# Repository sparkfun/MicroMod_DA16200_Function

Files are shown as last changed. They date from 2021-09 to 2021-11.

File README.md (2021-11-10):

SparkFun MicroMod DA16200 Function Board
========================================

SparkFun MicroMod DA16200 Function Board

[*SparkFun MicroMod DA16200 Function Board (18594)*](https://www.sparkfun.com/products/18594)

The SparkFun MicroMod DA16200 Function Board adds a fully integrated WiFi module with a 40MHz crystal oscillator, 32.768KHz RTC clock, RF Lumped RF filter, 4MB flash memory, and an on-board chip antenna to any MicroMod project. With the addition of JTAG connectors for deep dive programming, you've got everything you need to get your MicroMod setup ready for your next IoT project. 

The SparkFun MicroMod DA16200 Function Board is ideal for MicroMod projects involving door locks, thermostats, sensors, pet trackers, and other home IoT projects, thanks in part to the multiple sleep modes that allow you to take advantage of current draws as low as 0.2uA-3.5uA.

Additionally, the DA16200 module's certified WiFi alliance for IEEE802.11b/g/n, WiFi Direct, and WPS functionalities means that it has been approved for use by multiple countries and using the WiFi Alliance transfer policy, each WiFi Certification can be transferred without being tested again. 

Repository Contents
-------------------
* **/Hardware** - Eagle design files (.brd, .sch)

Documentation
--------------
* **[Hookup Guide](https://learn.sparkfun.com/tutorials/micromod-wifi-function-board---da16200-hookup-guide)** - Basic hookup guide for the SparkFun MicroMod DA16200 Function Board.

License Information
-------------------

This product is _**open source**_! 

Please review the LICENSE.md file for license information. 

If you have any questions or concerns on licensing, please contact technical support on our [SparkFun forums](https://forum.sparkfun.com/viewforum.php?f=152).

Distributed as-is; no warranty is given.

- Your friends at SparkFun.

_<COLLABORATION CREDIT>_

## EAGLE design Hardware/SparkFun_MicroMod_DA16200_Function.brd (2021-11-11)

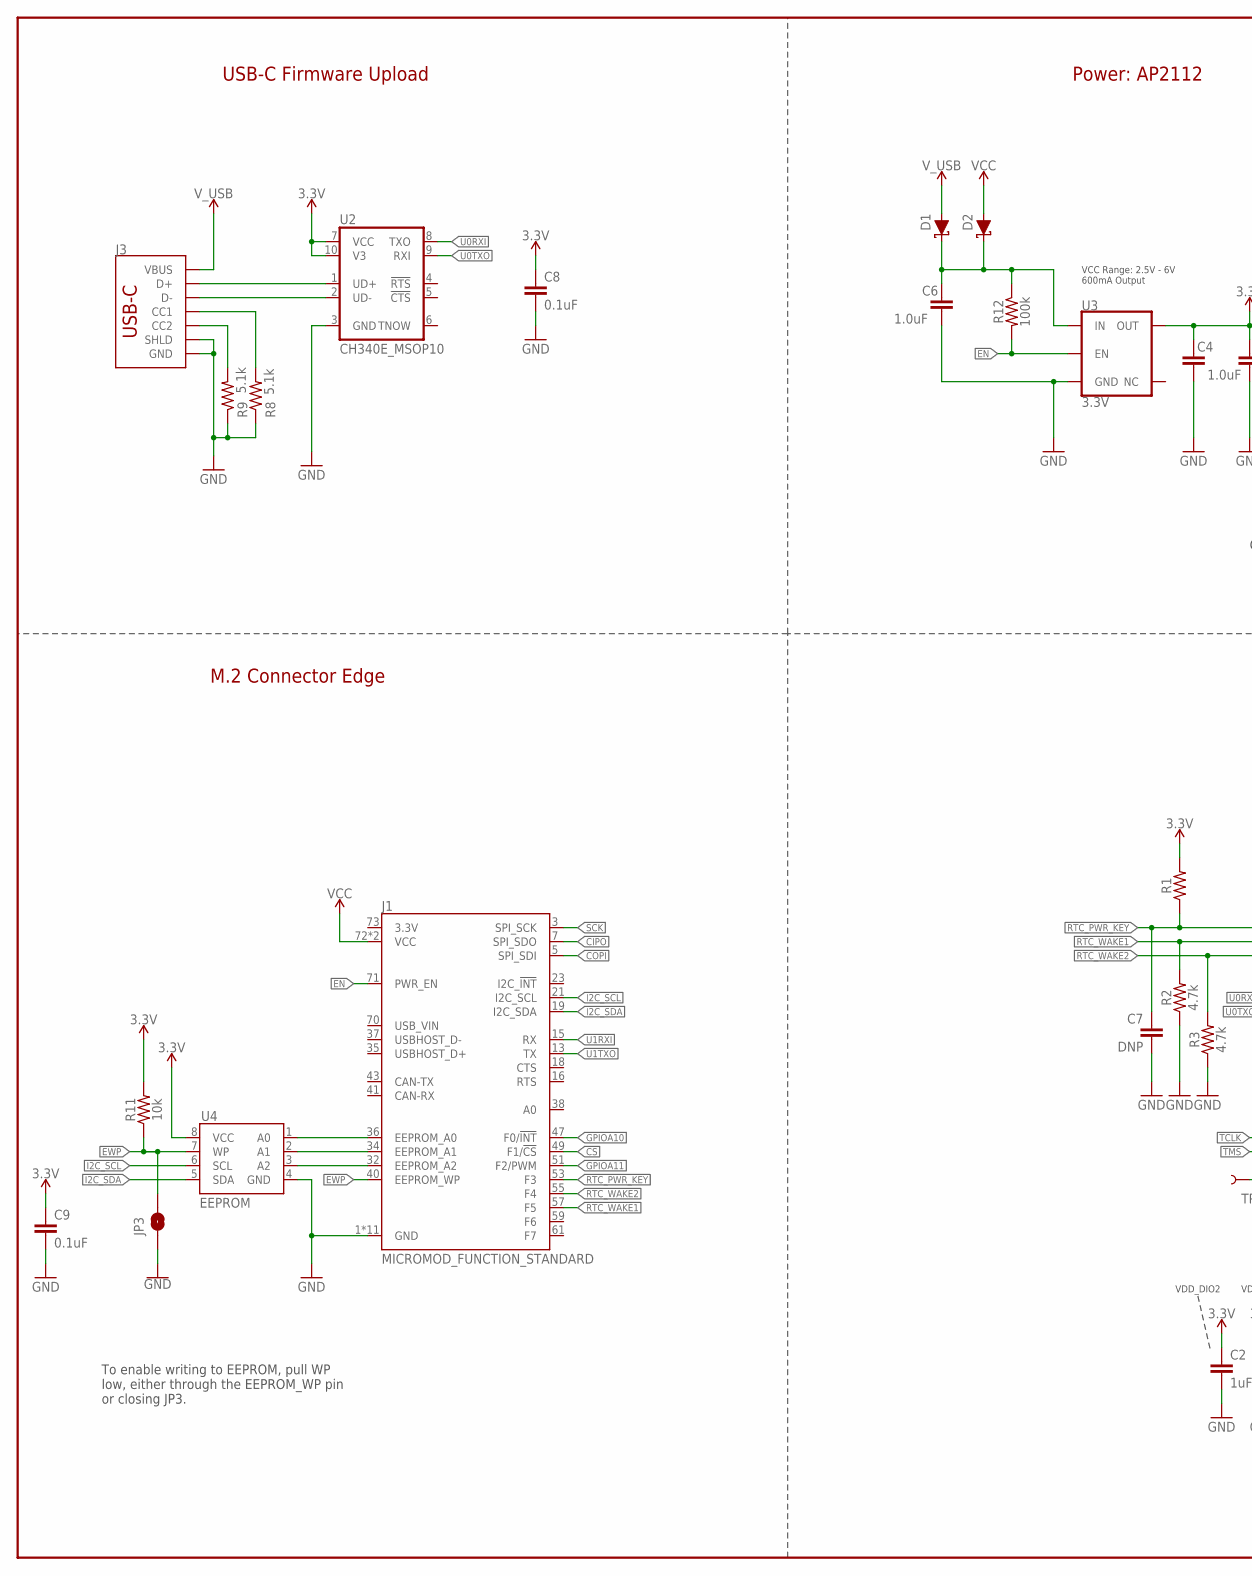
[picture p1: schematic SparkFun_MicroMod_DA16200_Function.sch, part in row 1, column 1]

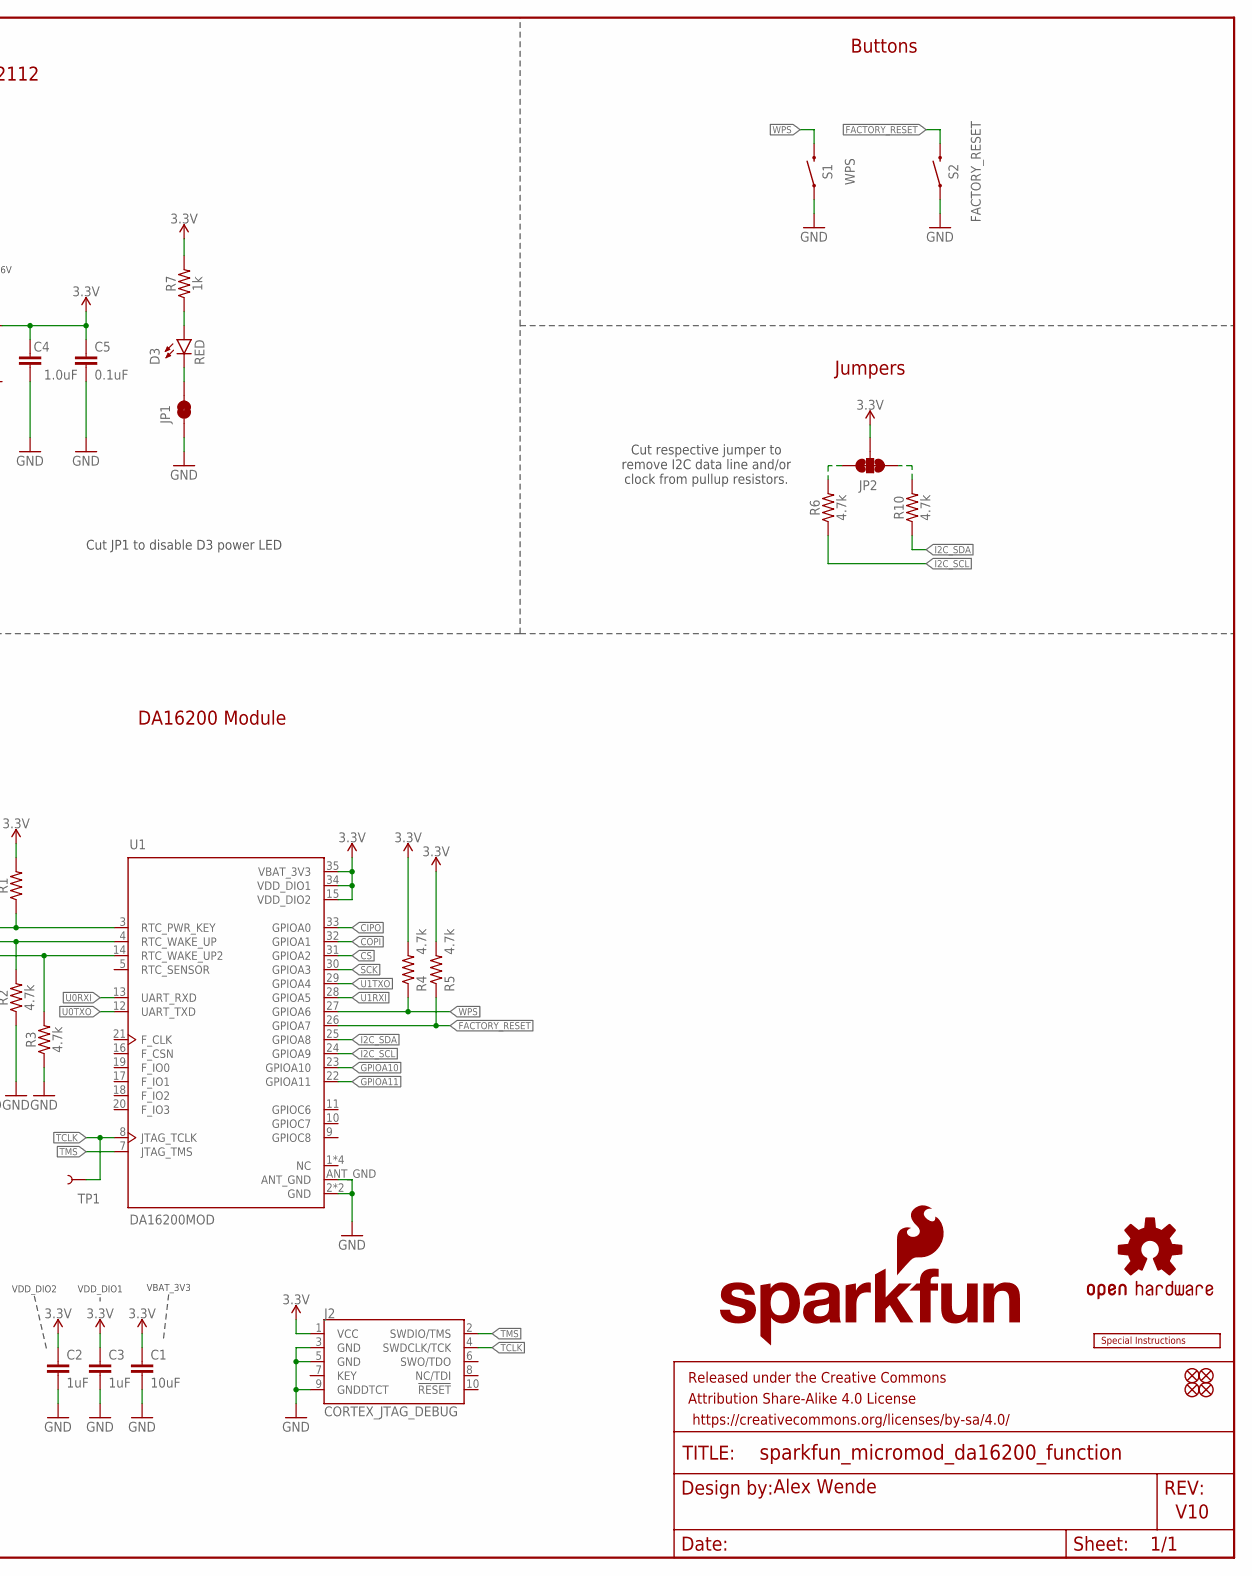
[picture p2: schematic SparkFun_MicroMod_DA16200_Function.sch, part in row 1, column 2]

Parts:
C1: 10uF; 0603
C2, C3: 1uF; 0603
C4, C6: 1.0uF; 0603
C5, C8, C9: 0.1uF; 0603
C7: DNP; 0603
D1, D2: DIODE-SCHOTTKY-BAT60A; SOD-323
D3: RED; LED-0603
FD1, FD2, FD3, FD4: FIDUCIAL1X2; FIDUCIAL-1X2
FRAME2: FRAME-LEDGER; CREATIVE_COMMONS
J1: MICROMOD_FUNCTION_STANDARD; M.2-CARD-E-22_FUNCTION_STANDARD
J2: CORTEX_JTAG_DEBUG; 2X5-PTH-1.27MM-NO_SILK
J3: USB_C_2-LAYER_PADS; USB-C-16P-2LAYER-PADS
JP1: JUMPER-SMT_2_NC_TRACE_SILK; SMT-JUMPER_2_NC_TRACE_SILK
JP2: JUMPER-SMT_3_2-NC_TRACE_SILK; SMT-JUMPER_3_2-NC_TRACE_SILK
JP3: JUMPER-SMT_2_NO_SILK; SMT-JUMPER_2_NO_SILK
LOGO1: SFE_LOGO_NAME_FLAME.2_INCH; SFE_LOGO_NAME_FLAME_.2
LOGO2: OSHW-LOGOS; OSHW-LOGO-S
LOGO3: SPECIAL_INSTRUCTIONS-ORDERING; ORDERING_INSTRUCTIONS
R1: 0603
R2, R3, R4, R5, R6, R10: 4.7k; 0603
R7: 1k; 0402-TIGHT
R8, R9: 5.1k; 0402-TIGHT
R11: 10k; 0603
R12: 100k; 0603
S1: WPS; TACTILE_SWITCH_SMD_5.2MM
S2: FACTORY_RESET; TACTILE_SWITCH_SMD_5.2MM
TP1: TEST-POINT3; PAD.03X.03
U1: DA16200MOD; XCVR_DA16200MOD-AAC4WA32
U2: CH340E_MSOP10; MSOP10
U3: 3.3V; SOT23-5
U4: EEPROM; SO08

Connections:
3.3V: C1.1, C2.1, C3.1, C4.1, C5.1, C8.1, C9.1, J2.1 (VCC), JP2.2, R1.2, R4.2, R5.2, R7.2, R11.2, U1.15 (VDD_DIO2), U1.34 (VDD_DIO1), U1.35 (VBAT_3V3), U2.7 (VCC), U2.10 (V3), U3.5 (OUT), U4.8 (VCC)
!CS!: J1.49 (F1/!CS!), U1.31 (GPIOA2)
CIPO: J1.7 (SPI_SDO), U1.33 (GPIOA0)
COPI: J1.5 (SPI_SDI), U1.32 (GPIOA1)
EN: J1.71 (PWR_EN), R12.2, U3.3 (EN)
EWP: J1.40 (EEPROM_WP), JP3.2, R11.1, U4.7 (WP)
FACTORY_RESET: R5.1, S2.3 (2), U1.26 (GPIOA7)
GND: C1.2, C2.2, C3.2, C4.2, C5.2, C6.2, C7.2, C8.2, C9.2, J1.1 (GND), J1.33 (GND), J1.39 (GND), J1.45 (GND), J1.75 (GND), J1.GND1 (GND), J1.GND2 (GND), J1.GND3 (GND), J1.GND4 (GND), J1.GND5 (GND), J1.GND6 (GND), J2.3 (GND), J2.5 (GND), J2.9 (GNDDTCT), J3.GND, J3.GND2 (GND), J3.SHLD1 (SHLD), J3.SHLD2 (SHLD), J3.SHLD3 (SHLD), J3.SHLD4 (SHLD), JP1.1, JP3.1, R2.1, R3.1, R8.1, R9.1, S1.1, S2.1, U1.2 (GND), U1.ANT_GND, U1.GND, U2.3 (GND), U3.2 (GND), U4.4 (GND)
GPIOA10: J1.47 (F0/!INT!), U1.23 (GPIOA10)
GPIOA11: J1.51 (F2/PWM), U1.22 (GPIOA11)
I2C_SCL: J1.21 (I2C_SCL), R6.1, U1.24 (GPIOA9), U4.6 (SCL)
I2C_SDA: J1.19 (I2C_SDA), R10.1, U1.25 (GPIOA8), U4.5 (SDA)
unnamed: J1.36 (EEPROM_A0), U4.1 (A0)
unnamed: J3.A5 (CC1), R8.2
unnamed: C6.1, D1.C, D2.C, R12.1, U3.1 (IN)
unnamed: J3.B5 (CC2), R9.2
unnamed: D3.C, JP1.2
unnamed: D3.A, R7.1
unnamed: J1.32 (EEPROM_A2), U4.3 (A2)
unnamed: J1.34 (EEPROM_A1), U4.2 (A1)
unnamed: J3.A6 (D+), J3.B6 (D+), U2.1 (UD+)
unnamed: J3.A7 (D-), J3.B7 (D-), U2.2 (UD-)
unnamed: JP2.1, R10.2
unnamed: JP2.3, R6.2
RTC_PWR_KEY: C7.1, J1.53 (F3), R1.1, U1.3 (RTC_PWR_KEY)
RTC_WAKE1: J1.57 (F5), R2.2, U1.4 (RTC_WAKE_UP)
RTC_WAKE2: J1.55 (F4), R3.2, U1.14 (RTC_WAKE_UP2)
SCK: J1.3 (SPI_SCK), U1.30 (GPIOA3)
TCLK: J2.4 (SWDCLK/TCK), TP1.1, U1.8 (JTAG_TCLK)
TMS: J2.2 (SWDIO/TMS), U1.7 (JTAG_TMS)
U0RXI: U1.13 (UART_RXD), U2.8 (TXO)
U0TXO: U1.12 (UART_TXD), U2.9 (RXI)
U1RXI: J1.15 (RX), U1.28 (GPIOA5)
U1TXO: J1.13 (TX), U1.29 (GPIOA4)
VCC: D2.A, J1.72 (VCC), J1.74 (VCC)
V_USB: D1.A, J3.VBUS1 (VBUS), J3.VBUS2 (VBUS)
WPS: R4.1, S1.3 (2), U1.27 (GPIOA6)

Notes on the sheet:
VCC Range: 2.5V - 6V 600mA Output
VDD_DIO2
VDD_DIO1
VBAT_3V3
Alex Wende
V10
USB-C Firmware Upload
DA16200 Module
M.2 Connector Edge
Power: AP2112
Buttons
Jumpers
Cut respective jumper to remove I2C data line and/or clock from pullup resistors.
To enable writing to EEPROM, pull WP low, either through the EEPROM_WP pin or closing JP3.
Cut JP1 to disable D3 power LED

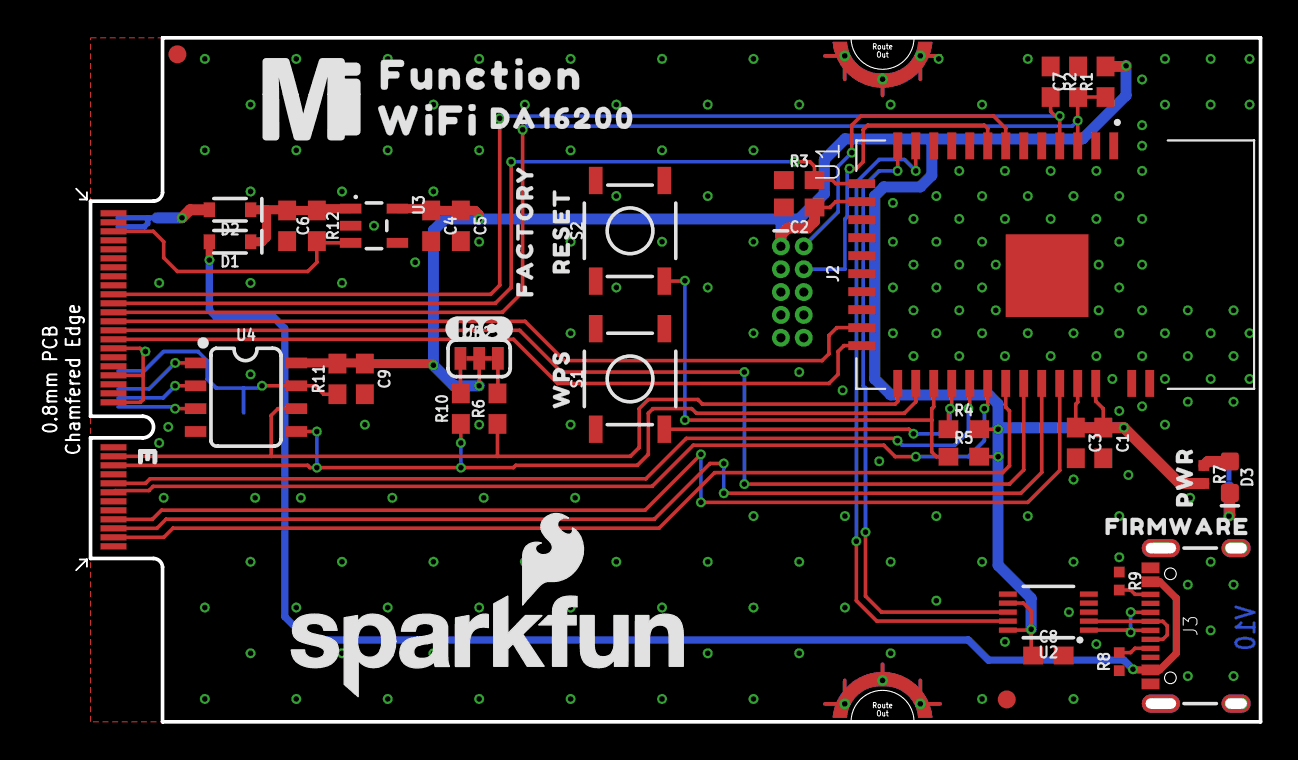
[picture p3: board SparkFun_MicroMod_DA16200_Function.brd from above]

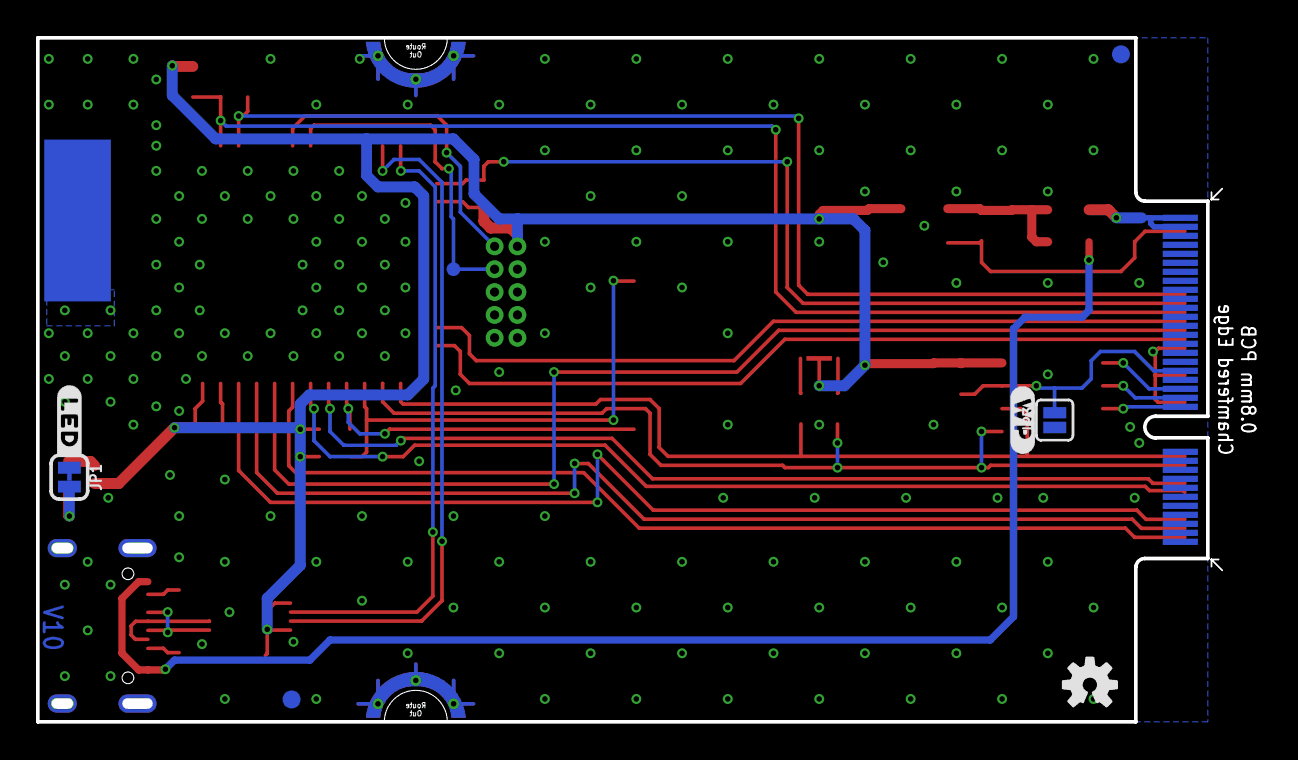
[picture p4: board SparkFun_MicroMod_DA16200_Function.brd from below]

Board: 2 copper layers, 65.8 x 38.0 mm, 57 parts (8 on the bottom side), 37 nets.

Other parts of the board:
U$1: FIRMWARE0
U$2: PWR0
U$3: #LED#0
U$4: FUNCTION0
U$5: DA162000
U$6: WIFI0
U$7: WPS0
U$8: FACTORY0
U$9: RESET0
U$10: #WP#0
U$11: #I2C#0
U$12: MICROMOD_MI_LOGO_1

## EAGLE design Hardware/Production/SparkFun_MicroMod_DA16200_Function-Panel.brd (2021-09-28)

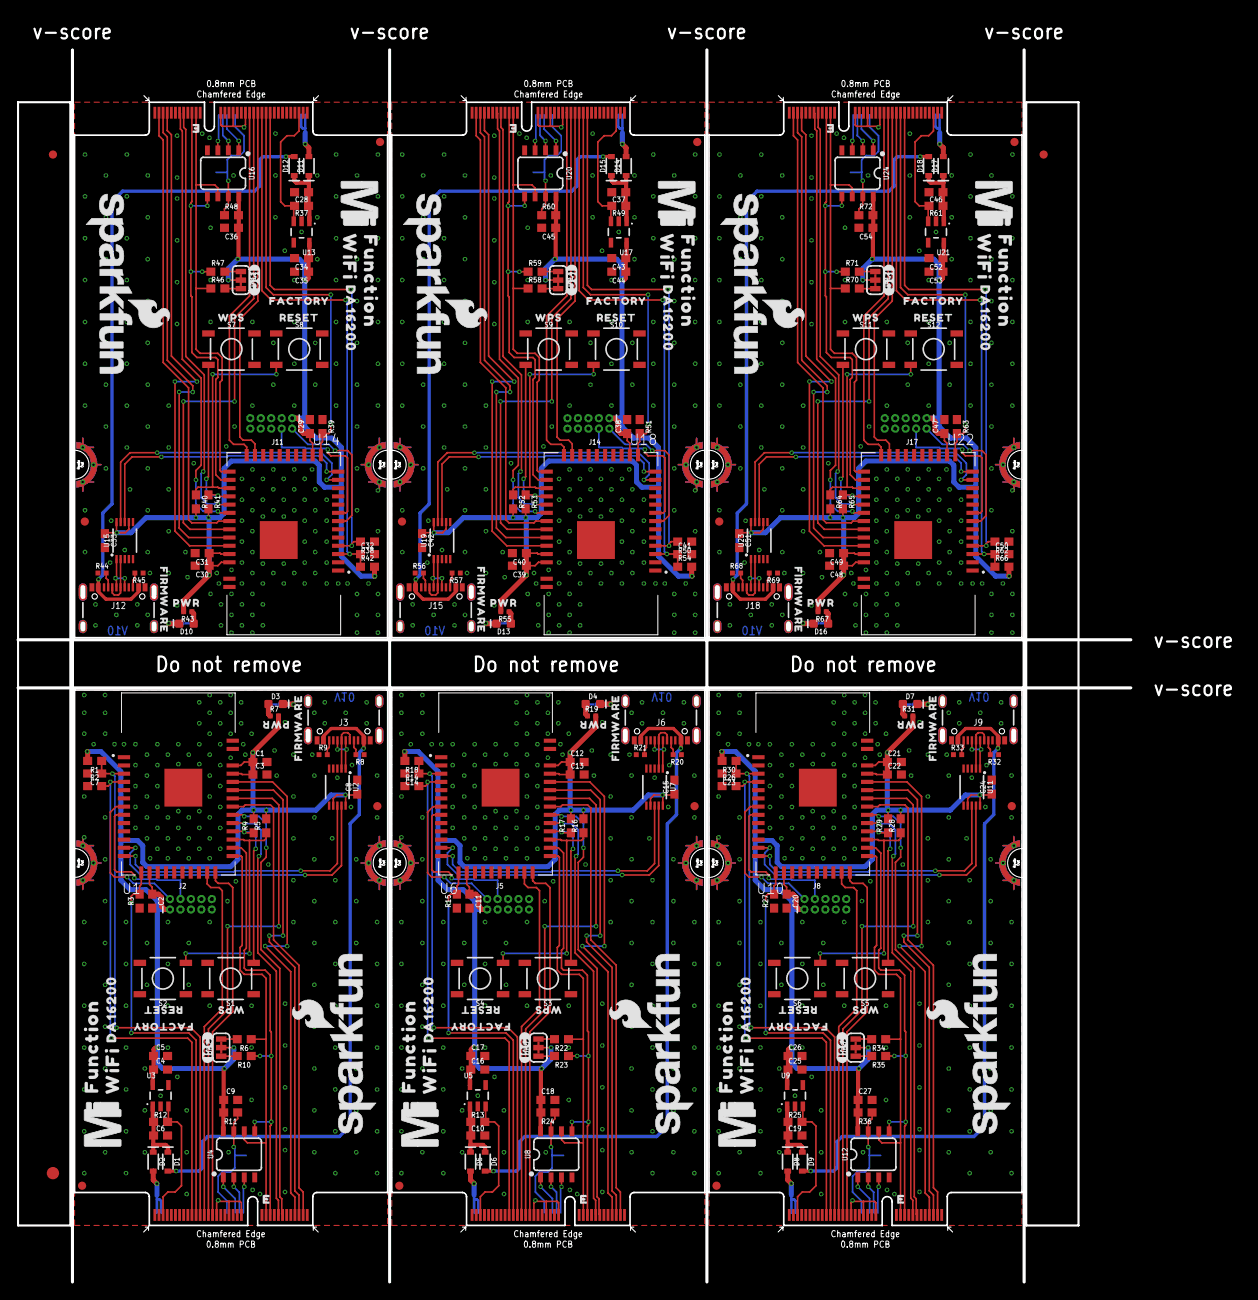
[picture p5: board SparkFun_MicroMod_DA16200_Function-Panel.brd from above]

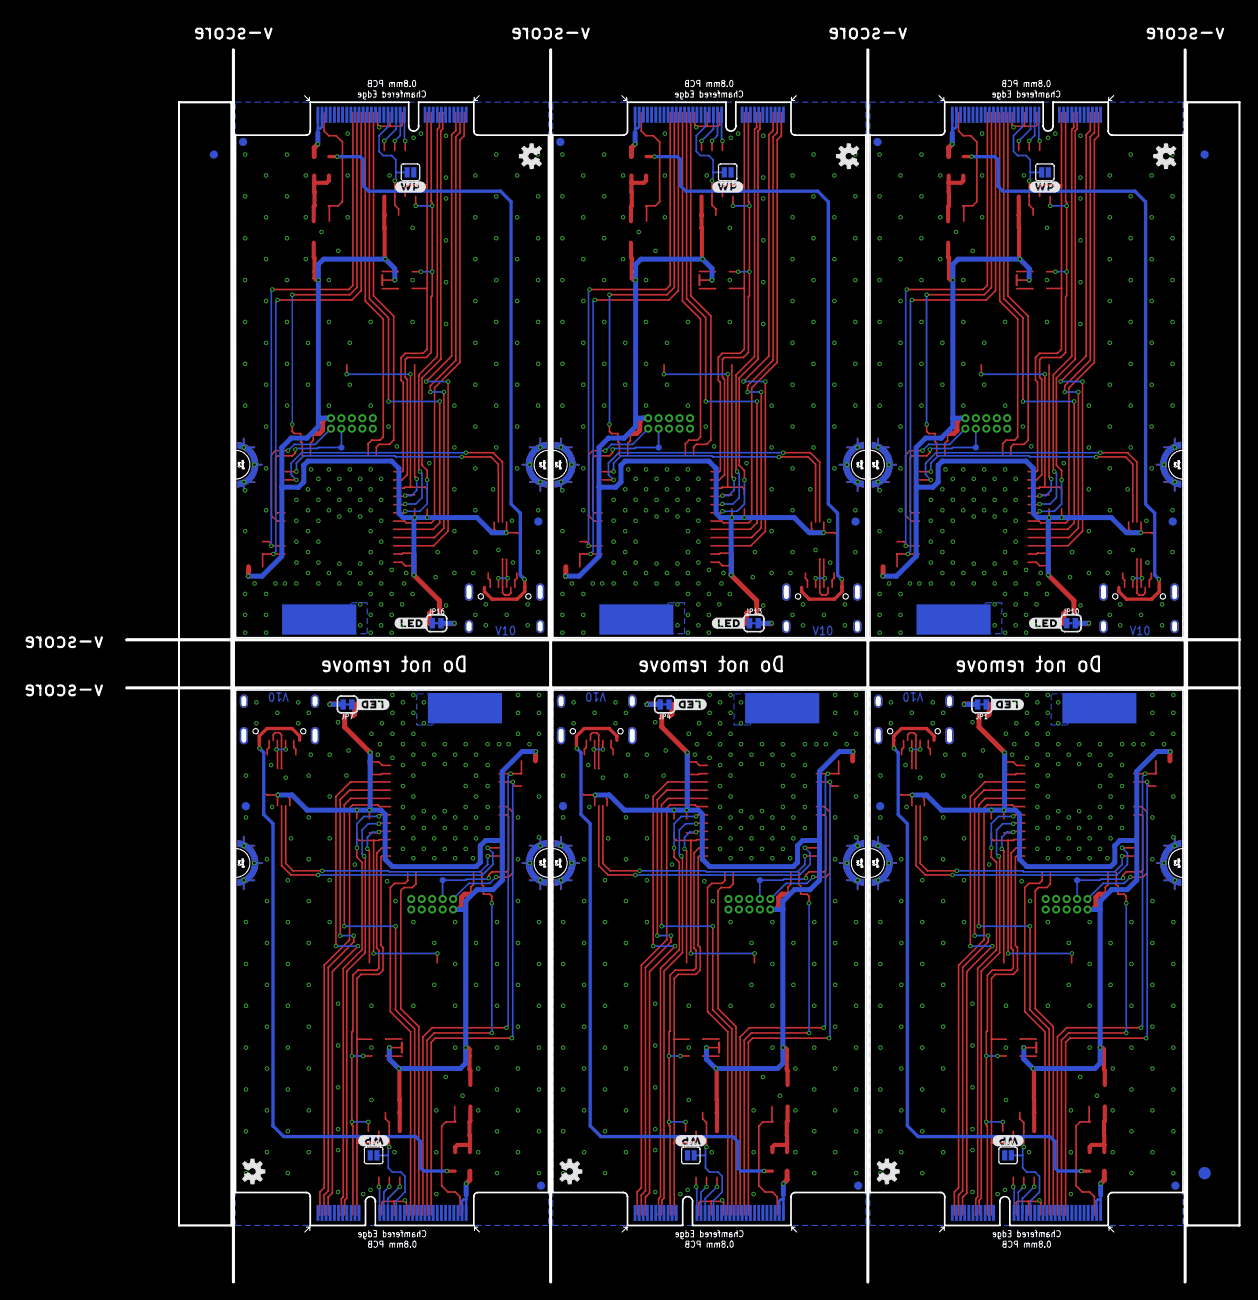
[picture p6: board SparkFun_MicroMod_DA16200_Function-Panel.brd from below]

Board: 2 copper layers, 135.1 x 149.6 mm, 336 parts (51 on the bottom side), 222 nets.

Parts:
C1, C12, C21, C30, C39, C48: 10uF; 0603
C2, C3, C11, C13, C20, C22, C29, C31, C38, C40, C47, C49: 1uF; 0603
C4, C6, C10, C16, C19, C25, C28, C34, C37, C43, C46, C52: 1.0uF; 0603
C5, C8, C9, C15, C17, C18, C24, C26, C27, C33, C35, C36, C42, C44, C45, C51, C53, C54: 0.1uF; 0603
C7, C14, C23, C32, C41, C50: DNP; 0603
D1, D2, D5, D6, D8, D9, D11, D12, D14, D15, D17, D18: SOD-323
D3, D4, D7, D10, D13, D16: RED; LED-0603
E$1, E$2, E$3, E$4: FIDUCIAL-1X2
E$5, E$6: FIDUCIAL-1.5X3
FD1, FD2, FD3, FD4, FD5, FD6, FD7, FD8, FD9, FD10, FD11, FD12, FD13, FD14, FD15, FD16, FD17, FD18, FD19, FD20, FD21, FD22, FD23, FD24: FIDUCIAL1X2; FIDUCIAL-1X2
J1, J4, J7, J10, J13, J16: MICROMOD_STANDARD; M.2-CARD-E-22_FUNCTION_STANDARD
J2, J5, J8, J11, J14, J17: CORTEX_JTAG_DEBUG; 2X5-PTH-1.27MM-NO_SILK
J3, J6, J9, J12, J15, J18: USB-C-16P-2LAYER-PADS
JP1, JP4, JP7, JP10, JP13, JP16: JUMPER-SMT_2_NC_TRACE_SILK; SMT-JUMPER_2_NC_TRACE_SILK
JP2, JP5, JP8, JP11, JP14, JP17: JUMPER-SMT_3_2-NC_TRACE_SILK; SMT-JUMPER_3_2-NC_TRACE_SILK
JP3, JP6, JP9, JP12, JP15, JP18: SMT-JUMPER_2_NO_SILK
LOGO1, LOGO3, LOGO5, LOGO7, LOGO9, LOGO11: SFE_LOGO_NAME_FLAME.2_INCH; SFE_LOGO_NAME_FLAME_.2
LOGO2, LOGO4, LOGO6, LOGO8, LOGO10, LOGO12: OSHW-LOGOS; OSHW-LOGO-S
R1, R18, R30, R42, R54, R66: DNP; 0603
R2, R3, R4, R5, R6, R10, R14, R15, R16, R17, R22, R23, R26, R27, R28, R29, R34, R35, R38, R39, R40, R41, R46, R47, R50, R51, R52, R53, R58, R59, R62, R63, R64, R65, R70, R71: 4.7k; 0603
R7, R19, R31, R43, R55, R67: 1k; 0402-TIGHT
R8, R9, R20, R21, R32, R33, R44, R45, R56, R57, R68, R69: 5.1k; 0402-TIGHT
R11, R24, R36, R48, R60, R72: 10k; 0603
R12, R13, R25, R37, R49, R61: 100k; 0603
S1, S3, S5, S7, S9, S11: WPS; TACTILE_SWITCH_SMD_5.2MM
S2, S4, S6, S8, S10, S12: FACTORY_RESET; TACTILE_SWITCH_SMD_5.2MM
TP1, TP2, TP3, TP4, TP5, TP6: PAD.03X.03
U1, U6, U10, U14, U18, U22: DA16200MOD; XCVR_DA16200MOD-AAC4WA32
U2, U7, U11, U15, U19, U23: CH340E_MSOP10; MSOP10
U3, U5, U9, U13, U17, U21: 3.3V; SOT23-5
U4, U8, U12, U16, U20, U24: EEPROM; SO08
U$1, U$13, U$25, U$37, U$49, U$61: FIRMWARE0
U$2, U$14, U$26, U$38, U$50, U$62: PWR0
U$3, U$15, U$27, U$39, U$51, U$63: #LED#0
U$4, U$16, U$28, U$40, U$52, U$64: FUNCTION0
U$5, U$17, U$29, U$41, U$53, U$65: DA162000
U$6, U$23, U$35, U$47, U$59, U$71: WIFI0
U$7, U$18, U$30, U$42, U$54, U$66: WPS0
U$8, U$19, U$31, U$43, U$55, U$67: FACTORY0
U$9, U$20, U$32, U$44, U$56, U$68: RESET0
U$10, U$24, U$36, U$48, U$60, U$72: #WP#0
U$11, U$21, U$33, U$45, U$57, U$69: #I2C#0
U$12, U$22, U$34, U$46, U$58, U$70: MICROMOD_MI_LOGO_1

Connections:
3.3V: C1.1, C2.1, C3.1, C4.1, C5.1, C8.1, C9.1, J2.1, JP2.2, R1.2, R4.2, R5.2, R7.2, R11.2, U1.15, U1.34, U1.35, U2.7, U2.10, U3.5, U4.8
3.3V1: C11.1, C12.1, C13.1, C15.1, C16.1, C17.1, C18.1, J5.1, JP5.2, R16.2, R17.2, R18.2, R19.2, R24.2, U5.5, U6.15, U6.34, U6.35, U7.7, U7.10, U8.8
3.3V2: C20.1, C21.1, C22.1, C24.1, C25.1, C26.1, C27.1, J8.1, JP8.2, R28.2, R29.2, R30.2, R31.2, R36.2, U9.5, U10.15, U10.34, U10.35, U11.7, U11.10, U12.8
3.3V3: C29.1, C30.1, C31.1, C33.1, C34.1, C35.1, C36.1, J11.1, JP11.2, R40.2, R41.2, R42.2, R43.2, R48.2, U13.5, U14.15, U14.34, U14.35, U15.7, U15.10, U16.8
3.3V4: C38.1, C39.1, C40.1, C42.1, C43.1, C44.1, C45.1, J14.1, JP14.2, R52.2, R53.2, R54.2, R55.2, R60.2, U17.5, U18.15, U18.34, U18.35, U19.7, U19.10, U20.8
3.3V5: C47.1, C48.1, C49.1, C51.1, C52.1, C53.1, C54.1, J17.1, JP17.2, R64.2, R65.2, R66.2, R67.2, R72.2, U21.5, U22.15, U22.34, U22.35, U23.7, U23.10, U24.8
!CS!: J1.49, U1.31
!CS!1: J4.49, U6.31
!CS!2: J7.49, U10.31
!CS!3: J10.49, U14.31
!CS!4: J13.49, U18.31
!CS!5: J16.49, U22.31
CIPO: J1.7, U1.33
CIPO1: J4.7, U6.33
CIPO2: J7.7, U10.33
CIPO3: J10.7, U14.33
CIPO4: J13.7, U18.33
CIPO5: J16.7, U22.33
COPI: J1.5, U1.32
COPI1: J4.5, U6.32
COPI2: J7.5, U10.32
COPI3: J10.5, U14.32
COPI4: J13.5, U18.32
COPI5: J16.5, U22.32
EN: J1.71, R12.2, U3.3
EN1: J4.71, R13.2, U5.3
EN2: J7.71, R25.2, U9.3
EN3: J10.71, R37.2, U13.3
EN4: J13.71, R49.2, U17.3
EN5: J16.71, R61.2, U21.3
EWP: J1.40, JP3.2, R11.1, U4.7
EWP1: J4.40, JP6.2, R24.1, U8.7
EWP2: J7.40, JP9.2, R36.1, U12.7
EWP3: J10.40, JP12.2, R48.1, U16.7
EWP4: J13.40, JP15.2, R60.1, U20.7
EWP5: J16.40, JP18.2, R72.1, U24.7
FACTORY_RESET: R5.1, S2.3, U1.26
FACTORY_RESET1: R16.1, S4.3, U6.26
FACTORY_RESET2: R28.1, S6.3, U10.26
FACTORY_RESET3: R40.1, S8.3, U14.26
FACTORY_RESET4: R52.1, S10.3, U18.26
FACTORY_RESET5: R64.1, S12.3, U22.26
GND: C1.2, C2.2, C3.2, C4.2, C5.2, C6.2, C7.2, C8.2, C9.2, J1.1, J1.33, J1.39, J1.45, J1.75, J1.GND1, J1.GND2, J1.GND3, J1.GND4, J1.GND5, J1.GND6, J2.3, J2.5, J2.9, J3.GND, J3.GND2, J3.SHLD1, J3.SHLD2, J3.SHLD3, J3.SHLD4, JP1.1, JP3.1, R2.1, R3.1, R8.1, R9.1, S1.1, S2.1, U1.2, U1.ANT_GND, U1.GND, U2.3, U3.2, U4.4
GND1: C10.2, C11.2, C12.2, C13.2, C14.2, C15.2, C16.2, C17.2, C18.2, J4.1, J4.33, J4.39, J4.45, J4.75, J4.GND1, J4.GND2, J4.GND3, J4.GND4, J4.GND5, J4.GND6, J5.3, J5.5, J5.9, J6.GND, J6.GND2, J6.SHLD1, J6.SHLD2, J6.SHLD3, J6.SHLD4, JP4.1, JP6.1, R14.1, R15.1, R20.1, R21.1, S3.1, S4.1, U5.2, U6.2, U6.ANT_GND, U6.GND, U7.3, U8.4
GND2: C19.2, C20.2, C21.2, C22.2, C23.2, C24.2, C25.2, C26.2, C27.2, J7.1, J7.33, J7.39, J7.45, J7.75, J7.GND1, J7.GND2, J7.GND3, J7.GND4, J7.GND5, J7.GND6, J8.3, J8.5, J8.9, J9.GND, J9.GND2, J9.SHLD1, J9.SHLD2, J9.SHLD3, J9.SHLD4, JP7.1, JP9.1, R26.1, R27.1, R32.1, R33.1, S5.1, S6.1, U9.2, U10.2, U10.ANT_GND, U10.GND, U11.3, U12.4
GND3: C28.2, C29.2, C30.2, C31.2, C32.2, C33.2, C34.2, C35.2, C36.2, J10.1, J10.33, J10.39, J10.45, J10.75, J10.GND1, J10.GND2, J10.GND3, J10.GND4, J10.GND5, J10.GND6, J11.3, J11.5, J11.9, J12.GND, J12.GND2, J12.SHLD1, J12.SHLD2, J12.SHLD3, J12.SHLD4, JP10.1, JP12.1, R38.1, R39.1, R44.1, R45.1, S7.1, S8.1, U13.2, U14.2, U14.ANT_GND, U14.GND, U15.3, U16.4
GND4: C37.2, C38.2, C39.2, C40.2, C41.2, C42.2, C43.2, C44.2, C45.2, J13.1, J13.33, J13.39, J13.45, J13.75, J13.GND1, J13.GND2, J13.GND3, J13.GND4, J13.GND5, J13.GND6, J14.3, J14.5, J14.9, J15.GND, J15.GND2, J15.SHLD1, J15.SHLD2, J15.SHLD3, J15.SHLD4, JP13.1, JP15.1, R50.1, R51.1, R56.1, R57.1, S9.1, S10.1, U17.2, U18.2, U18.ANT_GND, U18.GND, U19.3, U20.4
GND5: C46.2, C47.2, C48.2, C49.2, C50.2, C51.2, C52.2, C53.2, C54.2, J16.1, J16.33, J16.39, J16.45, J16.75, J16.GND1, J16.GND2, J16.GND3, J16.GND4, J16.GND5, J16.GND6, J17.3, J17.5, J17.9, J18.GND, J18.GND2, J18.SHLD1, J18.SHLD2, J18.SHLD3, J18.SHLD4, JP16.1, JP18.1, R62.1, R63.1, R68.1, R69.1, S11.1, S12.1, U21.2, U22.2, U22.ANT_GND, U22.GND, U23.3, U24.4
GPIOA1: J4.47, U6.23
GPIOA2: J4.51, U6.22
GPIOA3: J7.47, U10.23
GPIOA4: J7.51, U10.22
GPIOA5: J10.47, U14.23
GPIOA6: J10.51, U14.22
GPIOA7: J13.47, U18.23
GPIOA8: J13.51, U18.22
GPIOA9: J16.47, U22.23
GPIOA10: J1.47, U1.23
GPIOA11: J1.51, U1.22
GPIOA12: J16.51, U22.22
I2C_SCL: J1.21, R6.1, U1.24, U4.6
I2C_SCL1: J4.21, R22.1, U6.24, U8.6
I2C_SCL2: J7.21, R34.1, U10.24, U12.6
I2C_SCL3: J10.21, R46.1, U14.24, U16.6
I2C_SCL4: J13.21, R58.1, U18.24, U20.6
I2C_SCL5: J16.21, R70.1, U22.24, U24.6
I2C_SDA: J1.19, R10.1, U1.25, U4.5
I2C_SDA1: J4.19, R23.1, U6.25, U8.5
I2C_SDA2: J7.19, R35.1, U10.25, U12.5
I2C_SDA3: J10.19, R47.1, U14.25, U16.5
I2C_SDA4: J13.19, R59.1, U18.25, U20.5
I2C_SDA5: J16.19, R71.1, U22.25, U24.5
unnamed: J1.36, U4.1
unnamed: J3.A5, R8.2
unnamed: C6.1, D1.C, D2.C, R12.1, U3.1
unnamed: D4.C, JP4.2
unnamed: J3.B5, R9.2
unnamed: D3.C, JP1.2
unnamed: D3.A, R7.1
unnamed: J1.32, U4.3
unnamed: J1.34, U4.2
unnamed: J3.A6, J3.B6, U2.1
unnamed: J3.A7, J3.B7, U2.2
unnamed: D4.A, R19.1
unnamed: JP2.1, R10.2
unnamed: JP2.3, R6.2
unnamed: J6.A5, R20.2
unnamed: J6.B5, R21.2
unnamed: J6.A6, J6.B6, U7.1
unnamed: J6.A7, J6.B7, U7.2
unnamed: J4.32, U8.3
unnamed: J4.34, U8.2
unnamed: J4.36, U8.1
unnamed: JP5.1, R23.2
unnamed: JP5.3, R22.2
unnamed: C10.1, D5.C, D6.C, R13.1, U5.1
unnamed: D7.C, JP7.2
unnamed: D7.A, R31.1
unnamed: J9.A5, R32.2
unnamed: J9.B5, R33.2
unnamed: J9.A6, J9.B6, U11.1
unnamed: J9.A7, J9.B7, U11.2
unnamed: J7.32, U12.3
unnamed: J7.34, U12.2
unnamed: J7.36, U12.1
unnamed: JP8.1, R35.2
unnamed: JP8.3, R34.2
unnamed: C19.1, D8.C, D9.C, R25.1, U9.1
unnamed: D10.C, JP10.2
unnamed: D10.A, R43.1
unnamed: J12.A5, R44.2
unnamed: J12.B5, R45.2
unnamed: J12.A6, J12.B6, U15.1
unnamed: J12.A7, J12.B7, U15.2
unnamed: J10.32, U16.3
unnamed: J10.34, U16.2
unnamed: J10.36, U16.1
unnamed: JP11.1, R47.2
unnamed: JP11.3, R46.2
unnamed: C28.1, D11.C, D12.C, R37.1, U13.1
unnamed: D13.C, JP13.2
unnamed: D13.A, R55.1
unnamed: J15.A5, R56.2
unnamed: J15.B5, R57.2
unnamed: J15.A6, J15.B6, U19.1
unnamed: J15.A7, J15.B7, U19.2
unnamed: J13.32, U20.3
unnamed: J13.34, U20.2
unnamed: J13.36, U20.1
unnamed: JP14.1, R59.2
unnamed: JP14.3, R58.2
unnamed: C37.1, D14.C, D15.C, R49.1, U17.1
unnamed: D16.C, JP16.2
unnamed: D16.A, R67.1
unnamed: J18.A5, R68.2
unnamed: J18.B5, R69.2
unnamed: J18.A6, J18.B6, U23.1
unnamed: J18.A7, J18.B7, U23.2
unnamed: J16.32, U24.3
unnamed: J16.34, U24.2
unnamed: J16.36, U24.1
unnamed: JP17.1, R71.2
unnamed: JP17.3, R70.2
unnamed: C46.1, D17.C, D18.C, R61.1, U21.1
RTC_PWR_KEY: C7.1, J1.53, R1.1, U1.3
RTC_PWR_KEY1: C14.1, J4.53, R18.1, U6.3
RTC_PWR_KEY2: C23.1, J7.53, R30.1, U10.3
RTC_PWR_KEY3: C32.1, J10.53, R42.1, U14.3
RTC_PWR_KEY4: C41.1, J13.53, R54.1, U18.3
RTC_PWR_KEY5: C50.1, J16.53, R66.1, U22.3
RTC_WAKE1: J1.57, R2.2, U1.4
RTC_WAKE2: J1.55, R3.2, U1.14
RTC_WAKE3: J4.57, R14.2, U6.4
RTC_WAKE4: J4.55, R15.2, U6.14
RTC_WAKE5: J7.57, R26.2, U10.4
RTC_WAKE6: J7.55, R27.2, U10.14
RTC_WAKE7: J10.57, R38.2, U14.4
RTC_WAKE8: J10.55, R39.2, U14.14
RTC_WAKE9: J13.57, R50.2, U18.4
RTC_WAKE10: J13.55, R51.2, U18.14
RTC_WAKE11: J16.57, R62.2, U22.4
RTC_WAKE12: J16.55, R63.2, U22.14
SCK: J1.3, U1.30
SCK1: J4.3, U6.30
SCK2: J7.3, U10.30
SCK3: J10.3, U14.30
SCK4: J13.3, U18.30
SCK5: J16.3, U22.30
TCLK: J2.4, TP1.1, U1.8
TCLK1: J5.4, TP2.1, U6.8
TCLK2: J8.4, TP3.1, U10.8
TCLK3: J11.4, TP4.1, U14.8
TCLK4: J14.4, TP5.1, U18.8
TCLK5: J17.4, TP6.1, U22.8
TMS: J2.2, U1.7
TMS1: J5.2, U6.7
TMS2: J8.2, U10.7
TMS3: J11.2, U14.7
TMS4: J14.2, U18.7
TMS5: J17.2, U22.7
U0RXI: U1.13, U2.8
U0RXI1: U6.13, U7.8
U0RXI2: U10.13, U11.8
U0RXI3: U14.13, U15.8
U0RXI4: U18.13, U19.8
U0RXI5: U22.13, U23.8
U0TXO: U1.12, U2.9
U0TXO1: U6.12, U7.9
U0TXO2: U10.12, U11.9
U0TXO3: U14.12, U15.9
U0TXO4: U18.12, U19.9
U0TXO5: U22.12, U23.9
U1RXI: J1.15, U1.28
U1RXI1: J4.15, U6.28
U1RXI2: J7.15, U10.28
U1RXI3: J10.15, U14.28
U1RXI4: J13.15, U18.28
U1RXI5: J16.15, U22.28
U1TXO: J1.13, U1.29
U1TXO1: J4.13, U6.29
U1TXO2: J7.13, U10.29
U1TXO3: J10.13, U14.29
U1TXO4: J13.13, U18.29
U1TXO5: J16.13, U22.29
VCC: D2.A, J1.72, J1.74
VCC1: D5.A, J4.72, J4.74
VCC2: D8.A, J7.72, J7.74
VCC3: D11.A, J10.72, J10.74
VCC4: D14.A, J13.72, J13.74
VCC5: D17.A, J16.72, J16.74
V_USB: D1.A, J3.VBUS1, J3.VBUS2
V_USB1: D6.A, J6.VBUS1, J6.VBUS2
V_USB2: D9.A, J9.VBUS1, J9.VBUS2
V_USB3: D12.A, J12.VBUS1, J12.VBUS2
V_USB4: D15.A, J15.VBUS1, J15.VBUS2
V_USB5: D18.A, J18.VBUS1, J18.VBUS2
WPS: R4.1, S1.3, U1.27
WPS1: R17.1, S3.3, U6.27
WPS2: R29.1, S5.3, U10.27
WPS3: R41.1, S7.3, U14.27
WPS4: R53.1, S9.3, U18.27
WPS5: R65.1, S11.3, U22.27

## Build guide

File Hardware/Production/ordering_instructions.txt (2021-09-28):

panel size, 129x137mm
PCB thickness, 0.8mm
number of layers, 2
soldermask color, Red
silkscreen color, White
oz copper, 1oz
finish, ENIG
stencils, top
pcs per panel, 6
min trace width, 0.2032mm / 0.0080in
min drill size, 0.3048mm / 0.0120in

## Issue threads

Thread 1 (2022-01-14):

Product request: DA16200MOD based feather board

idea--list, 2022-01-14:
Took a look on the datasheet of the DA16200MOD module. It is not 100% clear to me if it would be possible to power down the Wi-Fi part while having the Cortex M4 chip available in active mode for doing computational stuff?

If that is possible this module would be a perfect fit for an ULP feather board that would log data to a uSD slot mounted just beneath the MCU. When logging is done, the Wi-Fi could be awakened for some seconds to do the data lifting and then put back to sleep. With a Qwiic connector, broken out SPI interface and cuttable jumpers for any power LEDs. 😇

If there is some room left, i would also add a NM180100 which would add BLE & LoRa capabilities (or instead just an nRf52840 for BLE long range) thus the product could be a universal ULP wireless gateway. For sure some clever pin design would be needed as both of these 2 modules have many pads (maybe the usual feather pins would break out the pads of the module with the lowest power consumption only in 1 direction and the pads of the second MCU would be broken out via a thight 4x6 pin matrix that would stack to an extension feather which would route the pin matrix to the conventional feather pin constellation just in the other direction on the Y-axis).

Such a board could compute a ton of data locally for extended periods of time while also transmit tons of data when needed despite operating from battery. 😉

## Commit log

2021-08-20 Update SparkFun_MicroMod_DA16200_Function.sch
    Added labels
    [SparkFun_MicroMod_DA16200_Function.sch]
2021-08-20 Update SparkFun_MicroMod_DA16200_Function.brd
    Added designer and measures
    [SparkFun_MicroMod_DA16200_Function.brd]
2021-08-23 Design Review Changes
    Swapped U1RX/TX
    Corrected SCL/SDA
    Added a few more vias on the PCB
    [SparkFun_MicroMod_DA16200_Function.brd, SparkFun_MicroMod_DA16200_Function.sch]
2021-08-23 Added Ordering Instructions
    [SparkFun_MicroMod_DA16200_Function.brd, SparkFun_MicroMod_DA16200_Function.sch]
2021-09-17 V10
    Added EEPROM, I2C Pullups
    [SparkFun_MicroMod_DA16200_Function.brd, SparkFun_MicroMod_DA16200_Function.sch]
2021-09-21 V10 update
    Added diodes for VIN and VUSB
    [SparkFun_MicroMod_DA16200_Function.brd, SparkFun_MicroMod_DA16200_Function.sch]
2021-09-24 V10 EEPROM changes
    Added pullup, jumper, and MM pin map for EEPROM WP pin
    [SparkFun_MicroMod_DA16200_Function.brd, SparkFun_MicroMod_DA16200_Function.sch]
2021-09-28 Added panel
    [SparkFun_MicroMod_DA16200_Function-Panel.GBL, SparkFun_MicroMod_DA16200_Function-Panel.GBO, SparkFun_MicroMod_DA16200_Function-Panel.GBP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]
2021-11-03 Updates function board symbol, fixes text that was not vector
    [SparkFun_MicroMod_DA16200_Function.brd, SparkFun_MicroMod_DA16200_Function.sch]
2021-11-11 Updates the design to use the Micromod-function device in the official SFE Eagle Libs
    [SparkFun_MicroMod_DA16200_Function.brd, SparkFun_MicroMod_DA16200_Function.sch]

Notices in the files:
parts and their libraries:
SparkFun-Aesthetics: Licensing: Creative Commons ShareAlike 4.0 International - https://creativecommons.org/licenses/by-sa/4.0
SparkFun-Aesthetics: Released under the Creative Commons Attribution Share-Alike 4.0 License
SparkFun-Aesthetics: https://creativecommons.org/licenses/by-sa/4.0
